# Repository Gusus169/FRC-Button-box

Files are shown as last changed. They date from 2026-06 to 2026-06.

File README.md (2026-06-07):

# FRC Button box
Reliability is critical in FIRST Robotics Competition (FRC), especially during matches where a single equipment failure can affect an entire game. One component that many teams depend on is a button box, which provides drivers with quick access to robot functions that would otherwise be difficult to control through a standard controller alone. Rather than relying on a commercially available solution, I decided to design a custom button box PCB tailored to my team's needs.

The goal of this project was to create a professional, competition-ready button box featuring plug-in terminals, an OLED display for testing and diagnostics, an indicator LED, and a large logo of my FRC Team 5402, Wreckless Robotics, integrated directly into the PCB design. Throughout the project, I researched existing button boxes used by other FRC teams, selected components through DigiKey, designed the schematic in KiCad, created the PCB layout, and prepared the board for manufacturing. Along the way, I learned more about PCB design, component libraries, footprint management, routing techniques, and design-for-manufacturing considerations.

This repository documents the complete development process, including planning, schematic design, PCB layout, manufacturing files, and project documentation. The finished design will be used to support driver practice and competition preparation for Team 5402 while providing a reliable and maintainable control interface for future seasons.

# 3D View of Final PCB Design-

Front-



Back-



# Key Features 
-Large Team Logo (very important)
-Flexibility – features 30 independent ports where buttons can be plugged in; no fixed sequence required, just plug-and-play

-Buttons can be swapped or replaced within a minute
  
-Uses a Raspberry Pi Pico (RP2040), allowing buttons to be programmed as needed for different FRC sessions

-Supports advanced logic such as button pairing and conditional inputs

-Designed for reliability – minimal excess components, reducing potential points of failure

-Includes an indicator LED for button box status

-Features a 0.91" OLED display for individual button testing and diagnostics

-Includes mounting holes to securely fasten the PCB in an enclosure or driver station setup

# Schematic & PCB DESIGN 

Schematic- 



PCB Front-



PCB Back-



# BOM

| Qty | Component | Value / Part Number |
| --- | --- | --- |
| 1 | OLED Display | SSD1306 0.91" 128×32 |
| 1 | LED | 3mm LED |
| 30  | Diode | 1N4148W |
| 6 | Terminal Block Connector | Phoenix 1792944 |
| 1 | Resistor | 330 Ω |
| 1 | Microcontroller | Raspberry Pi Pico (RP2040) |

# License

MIT

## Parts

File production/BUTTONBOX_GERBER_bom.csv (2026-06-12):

Designator | Footprint | Quantity | Value | LCSC Part #
BRD1 | SSD1306-0.91-OLED-4pin-128x32 | 1 | SSD1306
D1 | LED_D3.0mm | 1 | LED
D10, D11, D12, D13, D14, D15, D16, D17, D18, D19, D2, D20, D21, D22, D23, D24, D25, D26, D27, D28, D29, D3, D30, D31, D4, D5, D6, D7, D8, D9 | D_SOD-123 | 30 | 1N4148W
J1, J2, J3, J4, J5, J6 | PHOENIX_1792944 | 6 | 1792944
R1 | 0805 | 1 | 330 ohm
U1 | pi pico | 1 | SC0915

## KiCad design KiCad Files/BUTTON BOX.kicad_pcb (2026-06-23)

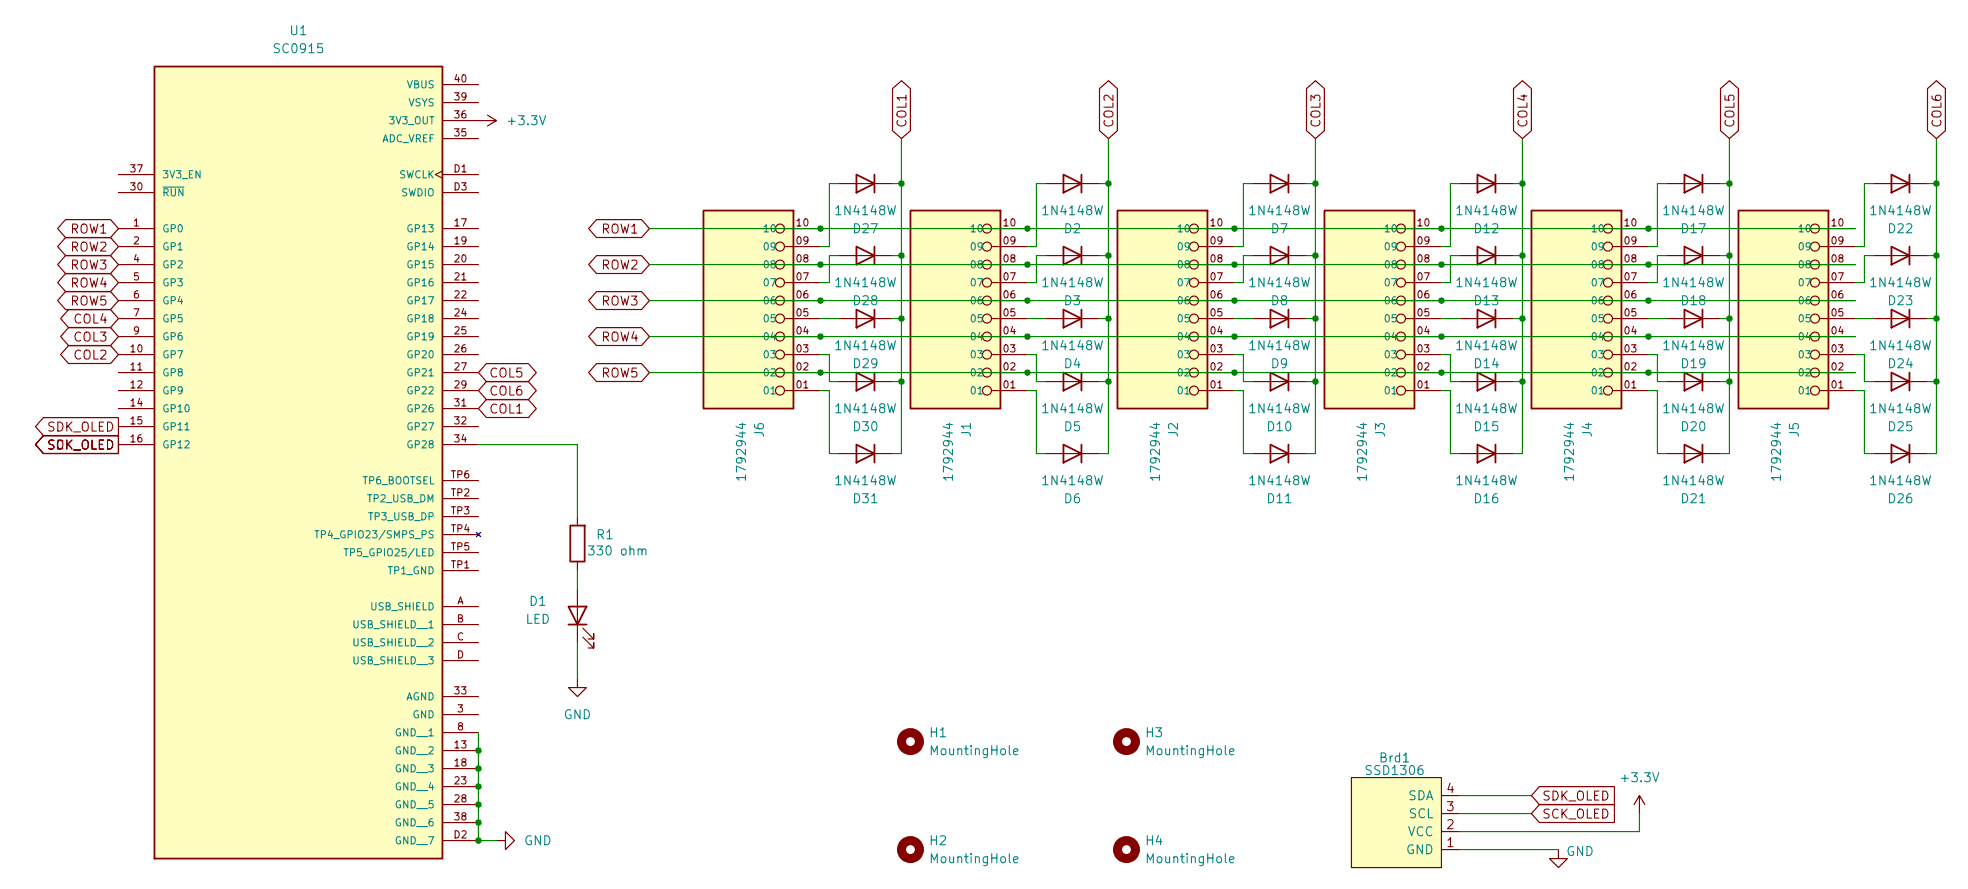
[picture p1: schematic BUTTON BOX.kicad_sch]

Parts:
Brd1: SSD1306; SSD1306-0.91-OLED-4pin-128x32
D1: LED; LED_D3.0mm
D2, D3, D4, D5, D6, D7, D8, D9, D10, D11, D12, D13, D14, D15, D16, D17, D18, D19, D20, D21, D22, D23, D24, D25, D26, D27, D28, D29, D30, D31: 1N4148W; D_SOD-123
H1, H2, H3, H4: MountingHole; MountingHole_3.2mm_M3
J1, J2, J3, J4, J5, J6: 1792944; PHOENIX_1792944; PARTREV 12.08.2015
R1: 330 ohm; R_0805_2012Metric_Pad1.20x1.40mm_HandSolder
U1: SC0915; RaspberryPi_Pico_Common_Unspecified; PARTREV 1.9

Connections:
+3.3V: Brd1.2 (VCC), U1.36 (3V3_OUT)
COL1: D27.1 (K), D28.1 (K), D29.1 (K), D30.1 (K), D31.1 (K), U1.31 (GP26)
COL2: D2.1 (K), D3.1 (K), D4.1 (K), D5.1 (K), D6.1 (K), U1.10 (GP7)
COL3: D7.1 (K), D8.1 (K), D9.1 (K), D10.1 (K), D11.1 (K), U1.9 (GP6)
COL4: D12.1 (K), D13.1 (K), D14.1 (K), D15.1 (K), D16.1 (K), U1.7 (GP5)
COL5: D17.1 (K), D18.1 (K), D19.1 (K), D20.1 (K), D21.1 (K), U1.27 (GP21)
COL6: D22.1 (K), D23.1 (K), D24.1 (K), D25.1 (K), D26.1 (K), U1.29 (GP22)
GND: Brd1.1 (GND), D1.1 (K), U1.8 (GND__1), U1.13 (GND__2), U1.18 (GND__3), U1.23 (GND__4), U1.28 (GND__5), U1.38 (GND__6), U1.D2 (GND__7)
unnamed: D1.2 (A), R1.1
unnamed: D2.2 (A), J1.09
unnamed: D3.2 (A), J1.07
unnamed: D4.2 (A), J1.05
unnamed: D5.2 (A), J1.03
unnamed: D6.2 (A), J1.01
unnamed: D7.2 (A), J2.09
unnamed: D8.2 (A), J2.07
unnamed: D9.2 (A), J2.05
unnamed: D10.2 (A), J2.03
unnamed: D11.2 (A), J2.01
unnamed: D12.2 (A), J3.09
unnamed: D13.2 (A), J3.07
unnamed: D14.2 (A), J3.05
unnamed: D15.2 (A), J3.03
unnamed: D16.2 (A), J3.01
unnamed: D17.2 (A), J4.09
unnamed: D18.2 (A), J4.07
unnamed: D19.2 (A), J4.05
unnamed: D20.2 (A), J4.03
unnamed: D21.2 (A), J4.01
unnamed: D22.2 (A), J5.09
unnamed: D23.2 (A), J5.07
unnamed: D24.2 (A), J5.05
unnamed: D25.2 (A), J5.03
unnamed: D26.2 (A), J5.01
unnamed: D27.2 (A), J6.09
unnamed: D28.2 (A), J6.07
unnamed: D29.2 (A), J6.05
unnamed: D30.2 (A), J6.03
unnamed: D31.2 (A), J6.01
unnamed: R1.2, U1.34 (GP28)
ROW1: J1.10, J2.10, J3.10, J4.10, J5.10, J6.10, U1.1 (GP0)
ROW2: J1.08, J2.08, J3.08, J4.08, J5.08, J6.08, U1.2 (GP1)
ROW3: J1.06, J2.06, J3.06, J4.06, J5.06, J6.06, U1.4 (GP2)
ROW4: J1.04, J2.04, J3.04, J4.04, J5.04, J6.04, U1.5 (GP3)
ROW5: J1.02, J2.02, J3.02, J4.02, J5.02, J6.02, U1.6 (GP4)

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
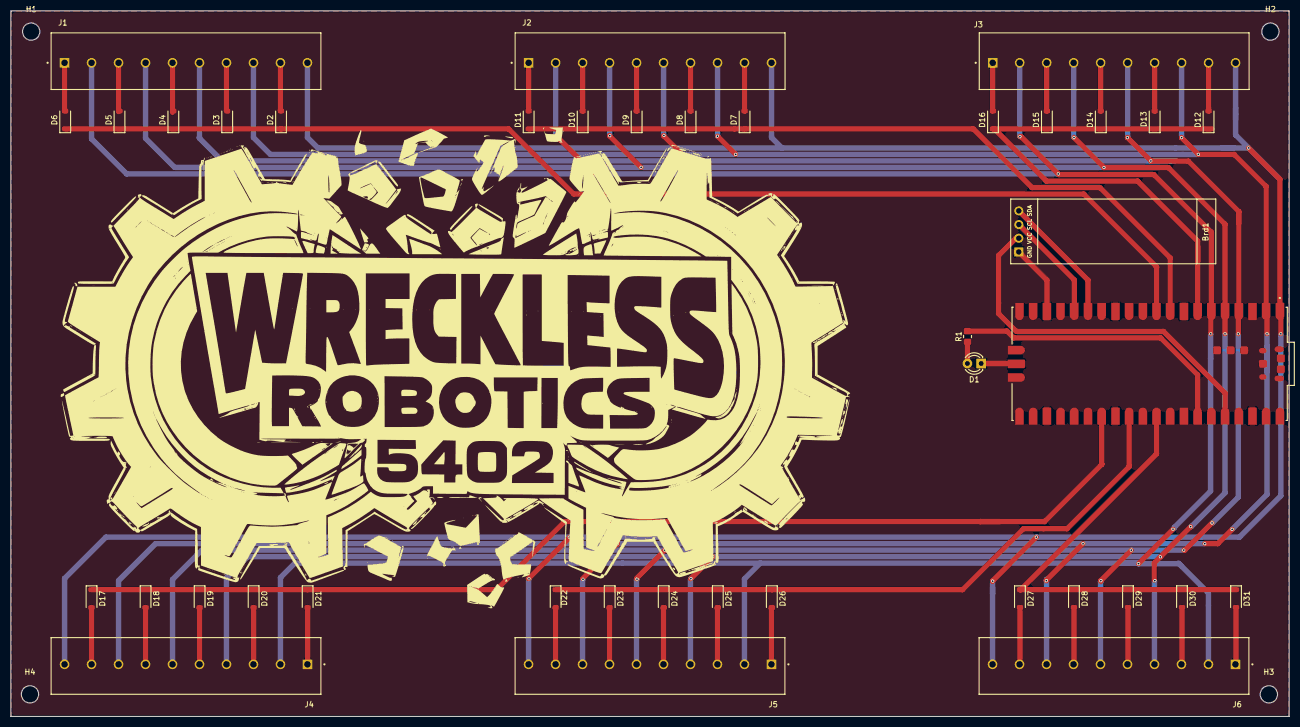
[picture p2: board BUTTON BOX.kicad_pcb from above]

Board: 2 copper layers, 236.8 x 130.7 mm, 44 parts (0 on the bottom side), 47 nets.

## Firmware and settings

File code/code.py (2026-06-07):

import time
import board
import digitalio
import busio
import usb_hid
import keypad
import displayio
import terminalio
from adafruit_display_text import label
import adafruit_displayio_ssd1306

# --- CUSTOM 32-BUTTON GAMEPAD DRIVER ---
class FRCGamepad:
    def __init__(self, devices):
        for device in devices:
            if device.usage == 0x05 and device.usage_page == 0x01:
                self._device = device
                break
        else:
            raise ValueError("Could not find Gamepad HID device. Check boot.py")
        self._report = bytearray(4) # 32 bits for 32 buttons
        
    def press(self, button):
        bit = button - 1
        self._report[bit // 8] |= 1 << (bit % 8)
        self._device.send_report(self._report)
        
    def release(self, button):
        bit = button - 1
        self._report[bit // 8] &= ~(1 << (bit % 8))
        self._device.send_report(self._report)

gp = FRCGamepad(usb_hid.devices)

# --- SETUP STATUS LED ---
led = digitalio.DigitalInOut(board.GP22)
led.direction = digitalio.Direction.OUTPUT
led.value = True # Solid glowing when connected and idle

# --- SETUP OLED DISPLAY ---
displayio.release_displays()
i2c = busio.I2C(scl=board.GP13, sda=board.GP12)
display_bus = displayio.I2CDisplay(i2c, device_address=0x3C)
display = adafruit_displayio_ssd1306.SSD1306(display_bus, width=128, height=64)

# Create text layout for OLED
splash = displayio.Group()
display.root_group = splash
oled_text = label.Label(terminalio.FONT, text="READY", color=0xFFFFFF, x=20, y=30, scale=3)
splash.append(oled_text)

# --- SETUP 5x6 HARDWARE MATRIX ---
# Rows: GP2 to GP6 | Cols: GP7 to GP11, plus GP15
row_pins = (board.GP2, board.GP3, board.GP4, board.GP5, board.GP6)
col_pins = (board.GP7, board.GP8, board.GP9, board.GP10, board.GP11, board.GP15)

# The keypad library runs in the background in C, making it incredibly fast and handles debouncing naturally
matrix = keypad.KeyMatrix(
    row_pins, col_pins,
    columns_to_anodes=False # Matches your 1N4148W diode orientation
)

print("FRC Button Box Initialized.")

# --- MAIN EVENT LOOP ---
while True:
    event = matrix.events.get()
    
    if event:
        # event.key_number maps the grid from 0 to 29. 
        # You requested buttons to output as 2 through 31.
        button_num = event.key_number + 2 
        
        if event.pressed:
            gp.press(button_num)
            oled_text.text = f"BTN {button_num}"
            # Turn LED off momentarily to create a "blink" effect when working
            led.value = False 
            
        elif event.released:
            gp.release(button_num)
            
            # If no other buttons are currently being held down, return to idle
            if matrix.pressed_count == 0:
                oled_text.text = "READY"
                led.value = True # Return to solid glow

    time.sleep(0.002) # Tiny delay to keep the loop stable

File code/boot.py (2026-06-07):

import usb_hid

# Custom HID Descriptor for a 32-Button Gamepad
# This is crucial for FRC so the Driver Station recognizes all 30 of your matrix buttons.
GAMEPAD_REPORT_DESCRIPTOR = bytes((
    0x05, 0x01,  # Usage Page (Generic Desktop Ctrls)
    0x09, 0x05,  # Usage (Game Pad)
    0xA1, 0x01,  # Collection (Application)
    0x85, 0x04,  #   Report ID (4)
    0x05, 0x09,  #   Usage Page (Button)
    0x19, 0x01,  #   Usage Minimum (Button 1)
    0x29, 0x20,  #   Usage Maximum (Button 32)
    0x15, 0x00,  #   Logical Minimum (0)
    0x25, 0x01,  #   Logical Maximum (1)
    0x75, 0x01,  #   Report Size (1)
    0x95, 0x20,  #   Report Count (32)
    0x81, 0x02,  #   Input (Data,Var,Abs,No Wrap,Linear,Preferred State,No Null Position)
    0xC0,        # End Collection
))

gamepad = usb_hid.Device(
    report_descriptor=GAMEPAD_REPORT_DESCRIPTOR,
    usage_page=0x01,
    usage=0x05,
    report_ids=(4,),
    in_report_lengths=(4,),
    out_report_lengths=(0,),
)

usb_hid.enable((gamepad,))

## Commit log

2026-06-07 All the KiCad Files
2026-06-07 README
    Updated project description and key features for the FRC Button Box.
2026-06-07 Firmware for the device
2026-06-12 Manufacturing ready files!
    [BUTTONBOX_GERBER_bom.csv, BUTTONBOX_GERBER_designators.csv, BUTTONBOX_GERBER_positions.csv]
2026-06-23 UN-ZIPPED Files
    [BUTTON BOX.kicad_pcb, BUTTON BOX.kicad_sch]
